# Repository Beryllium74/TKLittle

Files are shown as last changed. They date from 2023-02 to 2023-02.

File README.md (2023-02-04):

# TKLittle
My first custom keyboard layout, fully designed and created by me just as a fun learning experience.


The name TKLittle comes from the layout, inspiered by my 2 favorite layouts: Tkl and 40%(with a little opional HHKB-like bottom row thrown into in).


The pcb is made in Kicad 6 using Klepcbgen by Jeroen Bouwens as a starting point, but with a pro micro insted of an integrated chip.
kicad_Rwyfh4KZtf
kicad_9X1Wv6uTDP

The case is a top mounted stacked acrylic case made with the help of http://builder.swillkb.com/


Bottom layer, will be 3mm think in clear acrylic to show the bottom silkscreen of the pcb


Middle layer, 5mm thick frosted acrylic, with cutout wide enough to fit the pro micro so its closer to the edge so that it can use different cables easily


Plate, 3mm thick frosted acrylic, with 7u spacebar cutuouts and opion for non-HHKB layout


Top plate,5mm thick frosted acrylic with HHKB blockers.

The case should be mounted with 6 M2x18 bolts with nuts at the end, and for feen im gonna put some silicon feet instead of acyllic.

As i've said this is just a fun project, but i would like to learn from is it so i would if anyone with a bit more experience could give me some feedback on it before i spend the money to turn it into a reality
I have experience hand wiring multiple boards and ive made my own 3d printed cases before, so i kinda know what im doing, but its my first time working with Kicad so this is what im most worried about.

(obligatory language disclamer: english is not my first language so sorry if there are any spelling or grammar mistakes(but i do accept critisims as i need to get better)

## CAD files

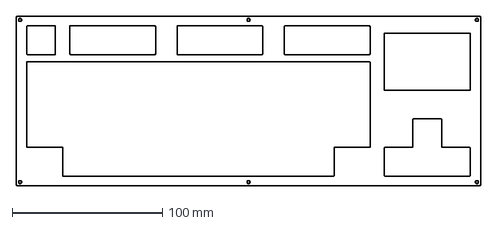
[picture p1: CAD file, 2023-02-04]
Top 5mm.dxf
309.3 x 113.0 mm

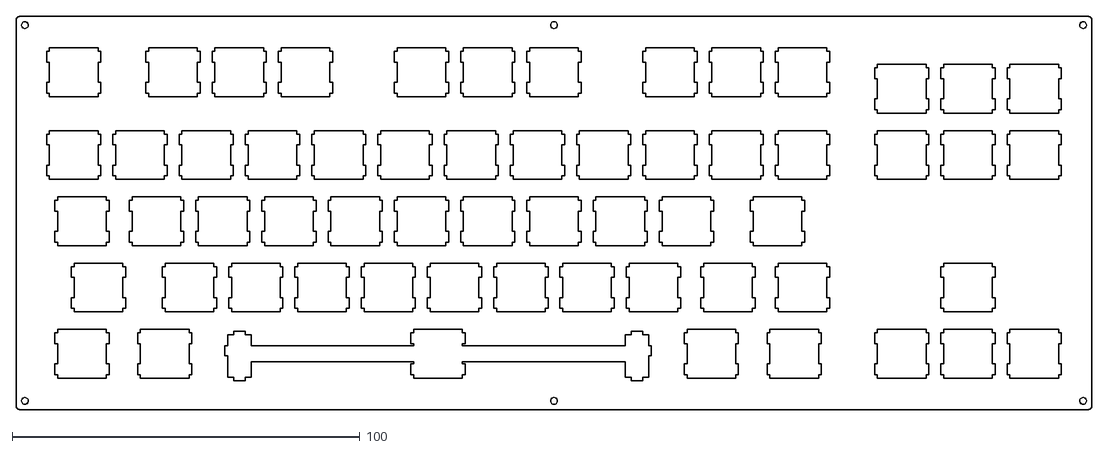
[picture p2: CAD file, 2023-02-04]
Plate 3mm.dxf
309.3 x 113.0

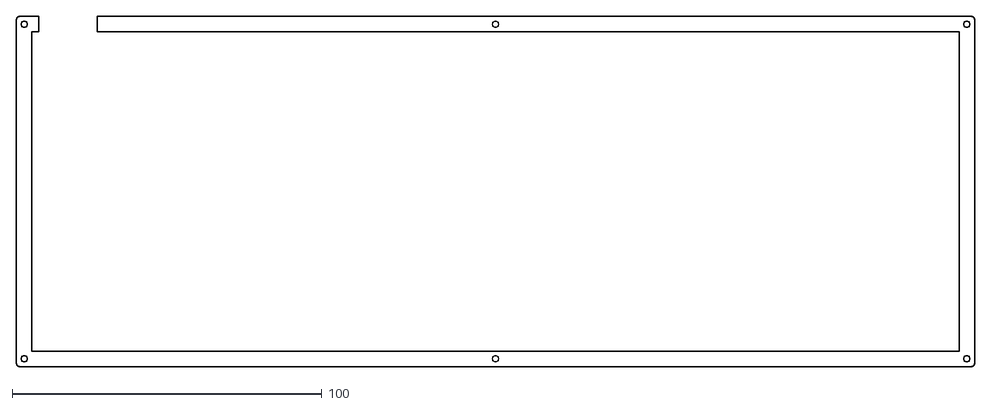
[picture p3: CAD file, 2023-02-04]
Mid 5mm.dxf
309.3 x 113.0

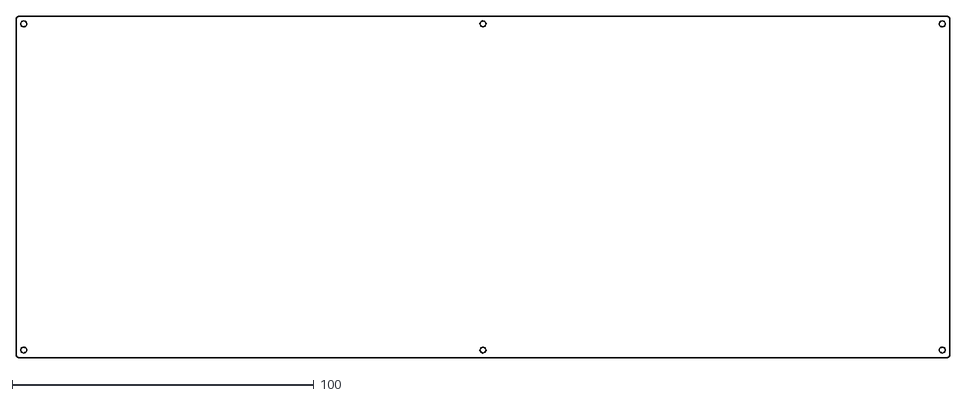
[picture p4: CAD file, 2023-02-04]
Bottom 3mm.dxf
309.3 x 113.0

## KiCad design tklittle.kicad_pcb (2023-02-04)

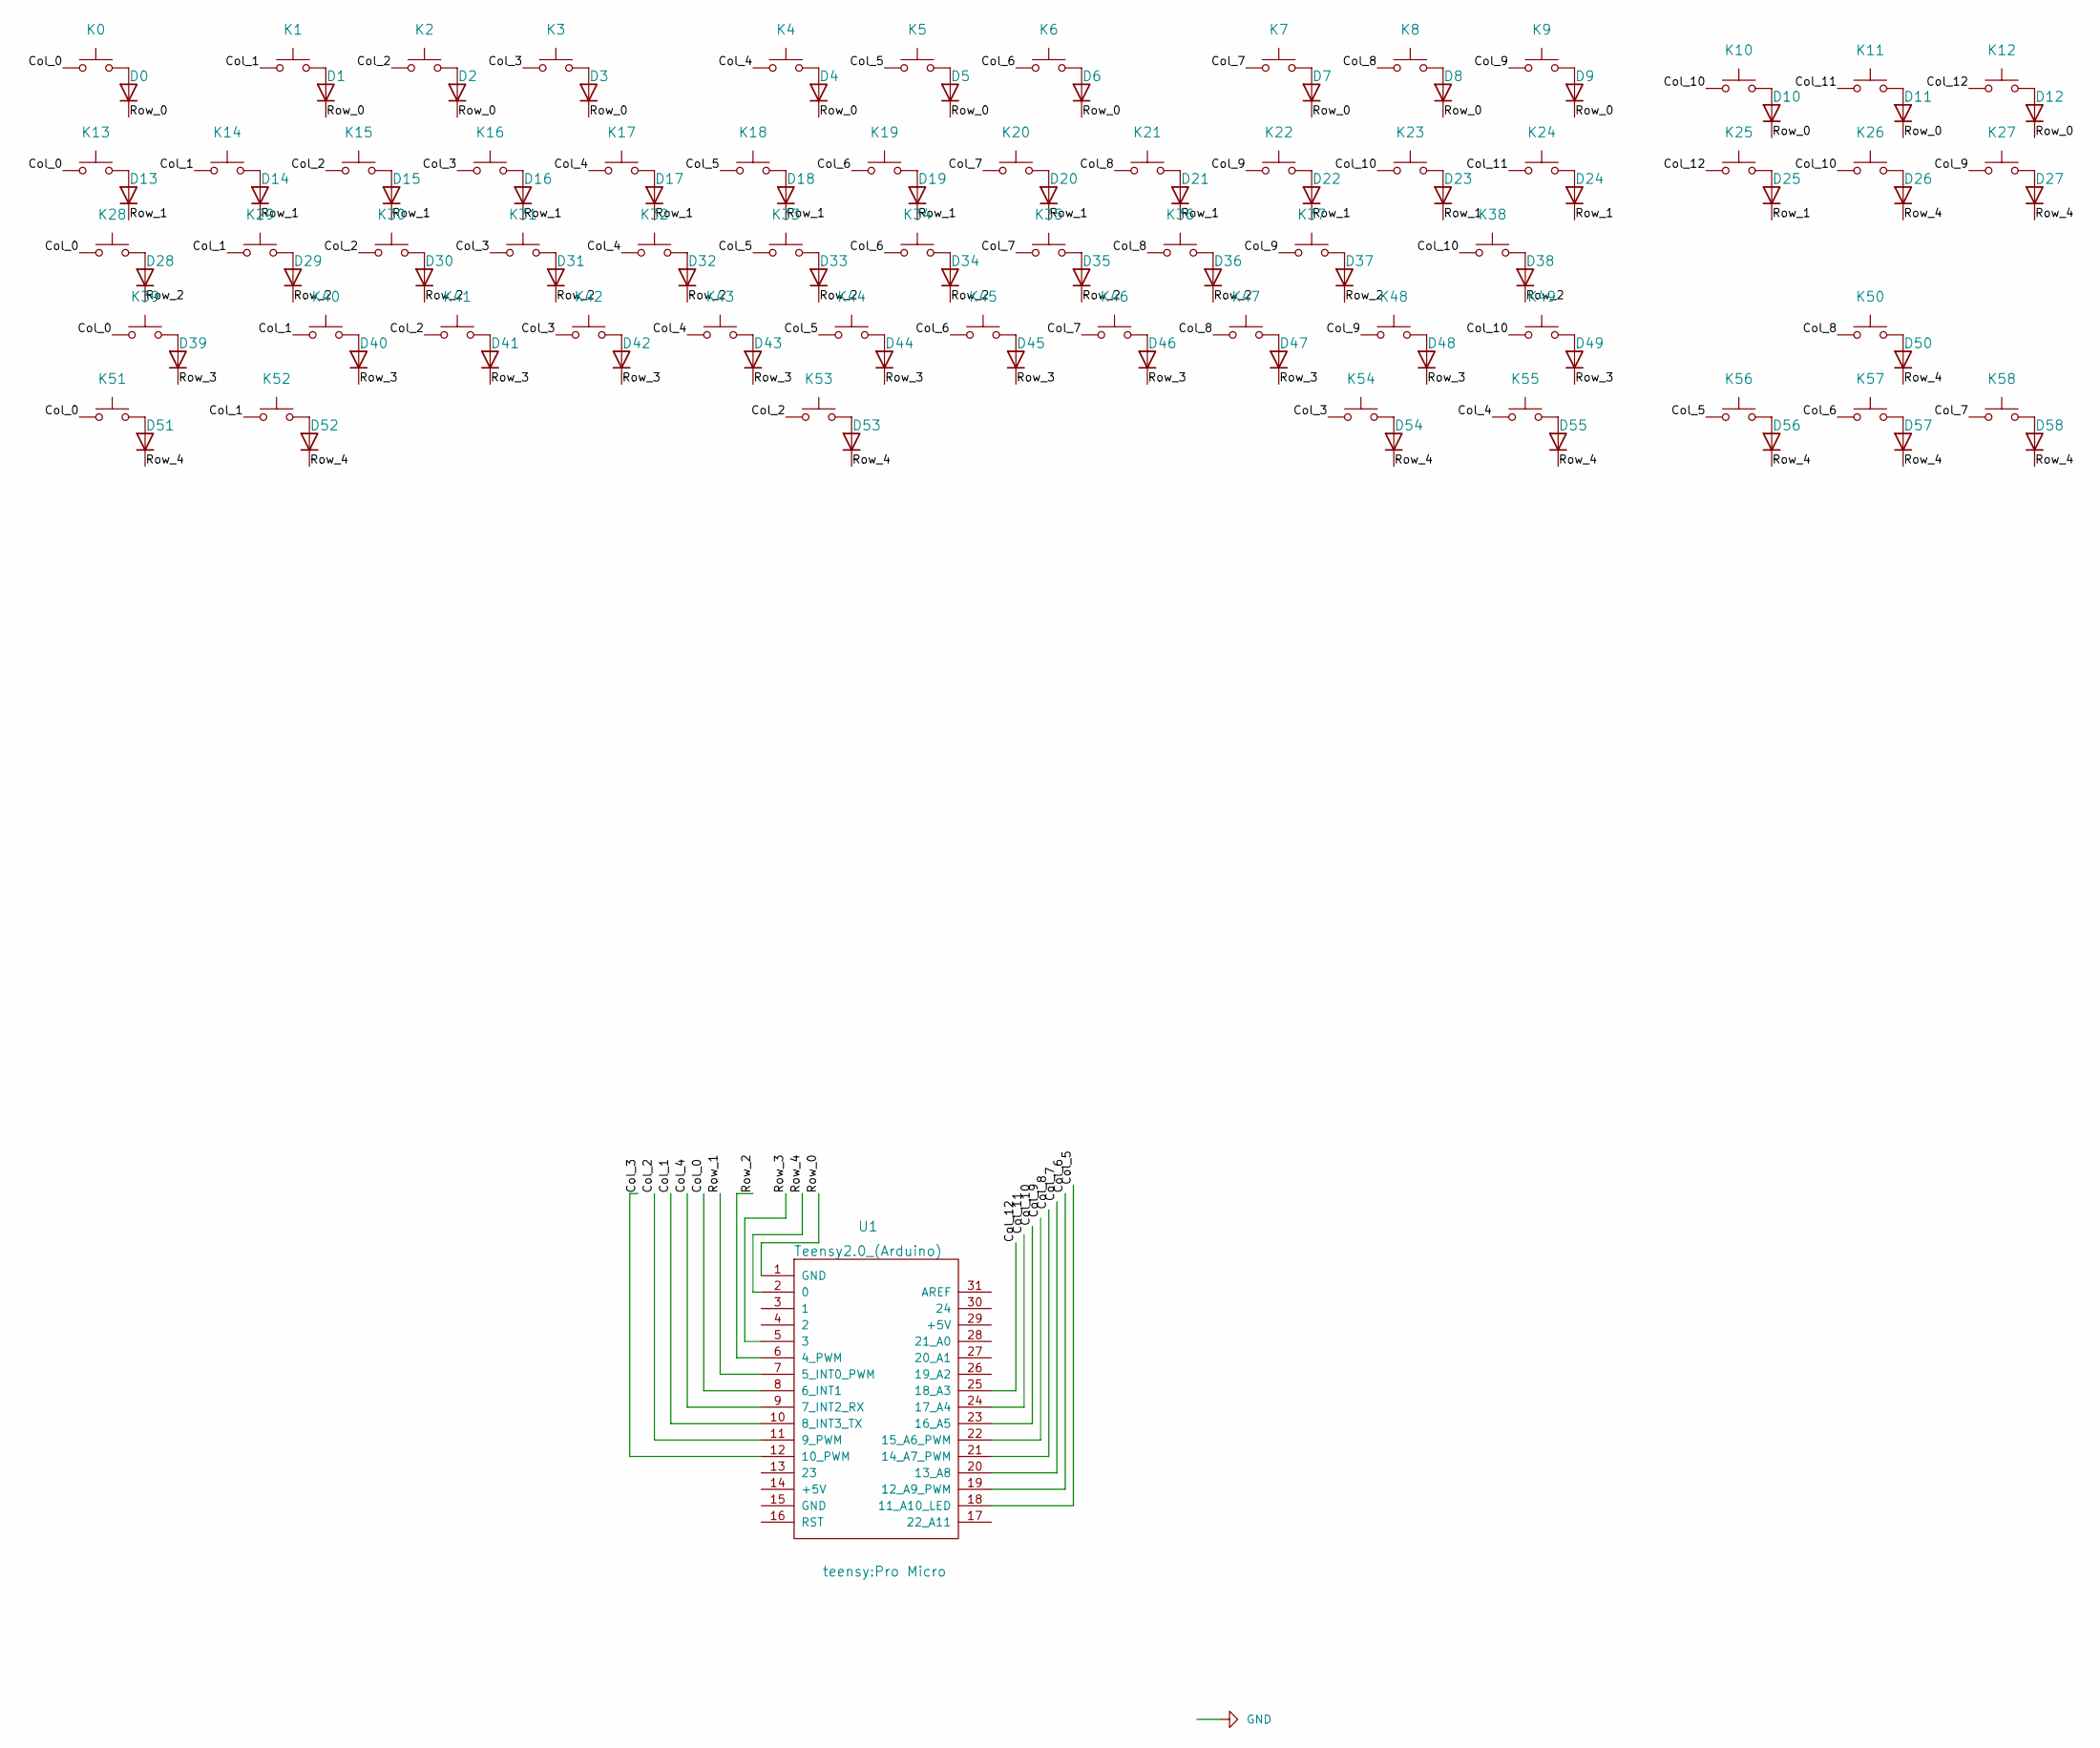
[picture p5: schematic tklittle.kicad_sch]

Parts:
D0, D1, D2, D3, D4, D5, D6, D7, D8, D9, D10, D11, D12, D13, D14, D15, D16, D17, D18, D19, D20, D21, D22, D23, D24, D25, D26, D27, D28, D29, D30, D31, D32, D33, D34, D35, D36, D37, D38, D39, D40, D41, D42, D43, D44, D45, D46, D47, D48, D49, D50, D51, D52, D53, D54, D55, D56, D57, D58: D; D_0805_2012Metric_Pad1.15x1.40mm_HandSolder
K0: 1; SW_Cherry_MX_1.00u_PCB
K1: 2; SW_Cherry_MX_1.00u_PCB
K2: 3; SW_Cherry_MX_1.00u_PCB
K3: 4; SW_Cherry_MX_1.00u_PCB
K4: 5; SW_Cherry_MX_1.00u_PCB
K5: 6; SW_Cherry_MX_1.00u_PCB
K6: 7; SW_Cherry_MX_1.00u_PCB
K7: 8; SW_Cherry_MX_1.00u_PCB
K8: 9; SW_Cherry_MX_1.00u_PCB
K9: 0; SW_Cherry_MX_1.00u_PCB
K10: insert; SW_Cherry_MX_1.00u_PCB
K11: Home; SW_Cherry_MX_1.00u_PCB
K12: Pgup; SW_Cherry_MX_1.00u_PCB
K13: Esc; SW_Cherry_MX_1.00u_PCB
K14: Q; SW_Cherry_MX_1.00u_PCB
K15: W; SW_Cherry_MX_1.00u_PCB
K16: E; SW_Cherry_MX_1.00u_PCB
K17: R; SW_Cherry_MX_1.00u_PCB
K18: T; SW_Cherry_MX_1.00u_PCB
K19: Y; SW_Cherry_MX_1.00u_PCB
K20: U; SW_Cherry_MX_1.00u_PCB
K21: I; SW_Cherry_MX_1.00u_PCB
K22: O; SW_Cherry_MX_1.00u_PCB
K23: P; SW_Cherry_MX_1.00u_PCB
K24: Back<br>Space; SW_Cherry_MX_1.00u_PCB
K25: Delete; SW_Cherry_MX_1.00u_PCB
K26: Emd; SW_Cherry_MX_1.00u_PCB
K27: PgDn; SW_Cherry_MX_1.00u_PCB
K28: Tab; SW_Cherry_MX_1.25u_PCB
K29: A; SW_Cherry_MX_1.00u_PCB
K30: S; SW_Cherry_MX_1.00u_PCB
K31: D; SW_Cherry_MX_1.00u_PCB
K32: F; SW_Cherry_MX_1.00u_PCB
K33: G; SW_Cherry_MX_1.00u_PCB
K34: H; SW_Cherry_MX_1.00u_PCB
K35: J; SW_Cherry_MX_1.00u_PCB
K36: K; SW_Cherry_MX_1.00u_PCB
K37: L; SW_Cherry_MX_1.00u_PCB
K38: Enter; SW_Cherry_MX_1.75u_PCB
K39: Shift; SW_Cherry_MX_1.75u_PCB
K40: Z; SW_Cherry_MX_1.00u_PCB
K41: X; SW_Cherry_MX_1.00u_PCB
K42: C; SW_Cherry_MX_1.00u_PCB
K43: V; SW_Cherry_MX_1.00u_PCB
K44: B; SW_Cherry_MX_1.00u_PCB
K45: N; SW_Cherry_MX_1.00u_PCB
K46: M; SW_Cherry_MX_1.00u_PCB
K47: <,.; SW_Cherry_MX_1.00u_PCB
K48: Shift; SW_Cherry_MX_1.25u_PCB
K49: Fn; SW_Cherry_MX_1.00u_PCB
K50: up; SW_Cherry_MX_1.00u_PCB
K51, K55: Super; SW_Cherry_MX_1.25u_PCB
K52, K54: Meta; SW_Cherry_MX_1.25u_PCB
K53: Blank; SW_Cherry_MX_6.25u_PCB
K56: left; SW_Cherry_MX_1.00u_PCB
K57: down; SW_Cherry_MX_1.00u_PCB
K58: right; SW_Cherry_MX_1.00u_PCB
U1: Teensy2.0_(Arduino); Pro Micro

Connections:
/Col_0: K0.1, K13.1, K28.1, K39.1, K51.1, U1.8 (6_INT1)
/Col_1: K1.1, K14.1, K29.1, K40.1, K52.1, U1.10 (8_INT3_TX)
/Col_2: K2.1, K15.1, K30.1, K41.1, K53.1, U1.11 (9_PWM)
/Col_3: K3.1, K16.1, K31.1, K42.1, K54.1, U1.12 (10_PWM)
/Col_4: K4.1, K17.1, K32.1, K43.1, K55.1, U1.9 (7_INT2_RX)
/Col_5: K5.1, K18.1, K33.1, K44.1, K56.1, U1.18 (11_A10_LED)
/Col_6: K6.1, K19.1, K34.1, K45.1, K57.1, U1.19 (12_A9_PWM)
/Col_7: K7.1, K20.1, K35.1, K46.1, K58.1, U1.20 (13_A8)
/Col_8: K8.1, K21.1, K36.1, K47.1, K50.1, U1.21 (14_A7_PWM)
/Col_9: K9.1, K22.1, K27.1, K37.1, K48.1, U1.22 (15_A6_PWM)
/Col_10: K10.1, K23.1, K26.1, K38.1, K49.1, U1.23 (16_A5)
/Col_11: K11.1, K24.1, U1.24 (17_A4)
/Col_12: K12.1, K25.1, U1.25 (18_A3)
/Row_0: D0.1 (K), D1.1 (K), D2.1 (K), D3.1 (K), D4.1 (K), D5.1 (K), D6.1 (K), D7.1 (K), D8.1 (K), D9.1 (K), D10.1 (K), D11.1 (K), D12.1 (K), U1.1 (GND)
/Row_1: D13.1 (K), D14.1 (K), D15.1 (K), D16.1 (K), D17.1 (K), D18.1 (K), D19.1 (K), D20.1 (K), D21.1 (K), D22.1 (K), D23.1 (K), D24.1 (K), D25.1 (K), U1.7 (5_INT0_PWM)
/Row_2: D28.1 (K), D29.1 (K), D30.1 (K), D31.1 (K), D32.1 (K), D33.1 (K), D34.1 (K), D35.1 (K), D36.1 (K), D37.1 (K), D38.1 (K), U1.6 (4_PWM)
/Row_3: D39.1 (K), D40.1 (K), D41.1 (K), D42.1 (K), D43.1 (K), D44.1 (K), D45.1 (K), D46.1 (K), D47.1 (K), D48.1 (K), D49.1 (K), U1.5 (3)
/Row_4: D26.1 (K), D27.1 (K), D50.1 (K), D51.1 (K), D52.1 (K), D53.1 (K), D54.1 (K), D55.1 (K), D56.1 (K), D57.1 (K), D58.1 (K), U1.2 (0)
unnamed: D0.2 (A), K0.2
unnamed: D1.2 (A), K1.2
unnamed: D2.2 (A), K2.2
unnamed: D3.2 (A), K3.2
unnamed: D4.2 (A), K4.2
unnamed: D5.2 (A), K5.2
unnamed: D6.2 (A), K6.2
unnamed: D7.2 (A), K7.2
unnamed: D8.2 (A), K8.2
unnamed: D9.2 (A), K9.2
unnamed: D10.2 (A), K10.2
unnamed: D11.2 (A), K11.2
unnamed: D12.2 (A), K12.2
unnamed: D13.2 (A), K13.2
unnamed: D14.2 (A), K14.2
unnamed: D15.2 (A), K15.2
unnamed: D16.2 (A), K16.2
unnamed: D17.2 (A), K17.2
unnamed: D18.2 (A), K18.2
unnamed: D19.2 (A), K19.2
unnamed: D20.2 (A), K20.2
unnamed: D21.2 (A), K21.2
unnamed: D22.2 (A), K22.2
unnamed: D23.2 (A), K23.2
unnamed: D24.2 (A), K24.2
unnamed: D25.2 (A), K25.2
unnamed: D26.2 (A), K26.2
unnamed: D27.2 (A), K27.2
unnamed: D28.2 (A), K28.2
unnamed: D29.2 (A), K29.2
unnamed: D30.2 (A), K30.2
unnamed: D31.2 (A), K31.2
unnamed: D32.2 (A), K32.2
unnamed: D33.2 (A), K33.2
unnamed: D34.2 (A), K34.2
unnamed: D35.2 (A), K35.2
unnamed: D36.2 (A), K36.2
unnamed: D37.2 (A), K37.2
unnamed: D38.2 (A), K38.2
unnamed: D39.2 (A), K39.2
unnamed: D40.2 (A), K40.2
unnamed: D41.2 (A), K41.2
unnamed: D42.2 (A), K42.2
unnamed: D43.2 (A), K43.2
unnamed: D44.2 (A), K44.2
unnamed: D45.2 (A), K45.2
unnamed: D46.2 (A), K46.2
unnamed: D47.2 (A), K47.2
unnamed: D48.2 (A), K48.2
unnamed: D49.2 (A), K49.2
unnamed: D50.2 (A), K50.2
unnamed: D51.2 (A), K51.2
unnamed: D52.2 (A), K52.2
unnamed: D53.2 (A), K53.2
unnamed: D54.2 (A), K54.2
unnamed: D55.2 (A), K55.2
unnamed: D56.2 (A), K56.2
unnamed: D57.2 (A), K57.2
unnamed: D58.2 (A), K58.2

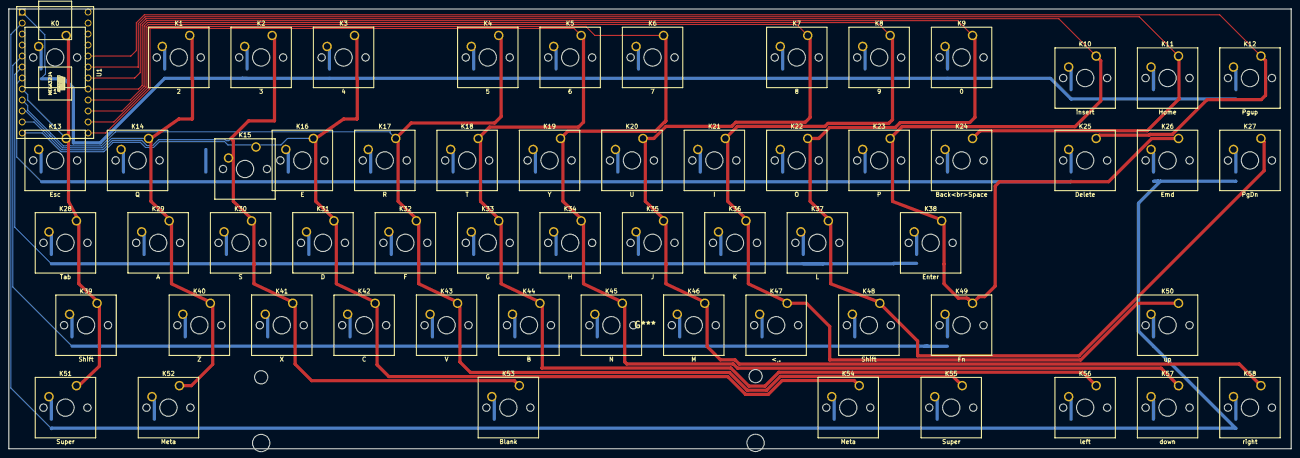
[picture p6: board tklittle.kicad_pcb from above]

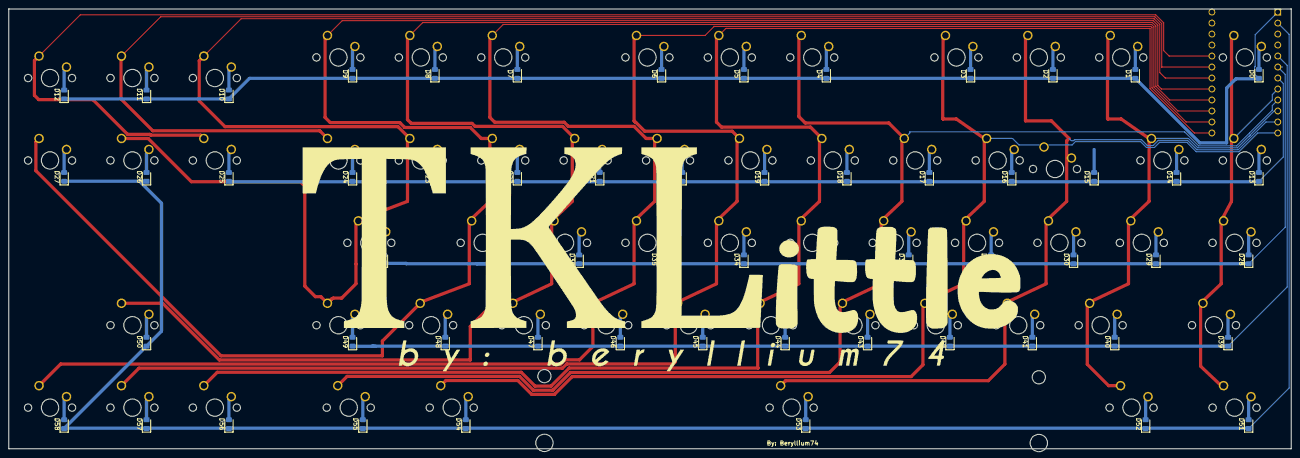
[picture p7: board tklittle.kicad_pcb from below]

Board: 2 copper layers, 296.5 x 101.7 mm, 119 parts (59 on the bottom side), 77 nets.
